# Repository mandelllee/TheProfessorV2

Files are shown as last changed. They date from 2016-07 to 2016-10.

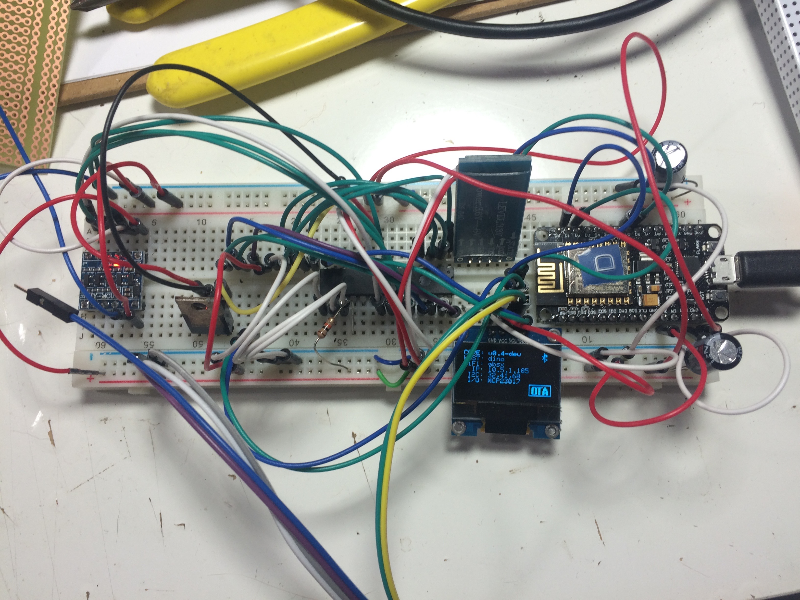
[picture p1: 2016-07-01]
images/IMG_1917.jpg

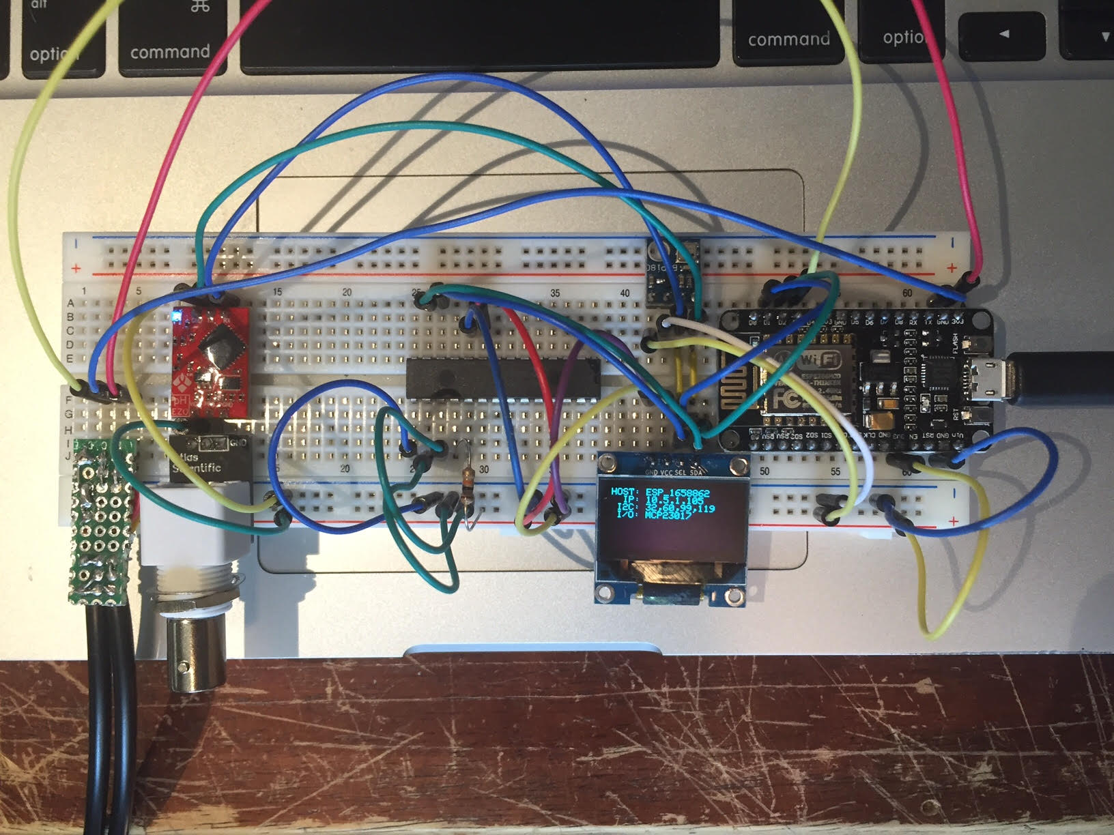
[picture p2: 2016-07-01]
images/breadboard_leaflift_alpha.jpg

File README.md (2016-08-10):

#Arduino-core for leaflift platform

# Setup #
1. Install USB drivers [CP210x USB to UART Bridge VCP Drivers](https://www.silabs.com/products/mcu/Pages/USBtoUARTBridgeVCPDrivers.aspx)
2. Copy libraries to ~/Documents/Arduino/library/ 

# Supported Boards #
* NodeMCU 1.0 (ESP8266-12E)
* Adafruit HUZZAH (ESP8266-12E)

# Uploading to boards - Step by step  #

## NodeMCU 1.0 (ESP-12E Module) ##
0. arduino ide board manager
    http://arduino.esp8266.com/versions/2.2.0/package_esp8266com_index.json
    https://adafruit.github.io/arduino-board-index/package_adafruit_index.json
1. Select board from Tools > Board:
2. Click ( > ) to upload, board will reset when done

##  Adafruit HUZZAH ESP8266 ##
1. Select board from Tools > Board:
2. Put the Board in program mode on bootloader 
*(hold GPIO0 button then bress reset holding GPIO0 till after reset is released)*
3. Click ( > ) to upload, board will reset when done

# Tools for graphics #
[Tool for creating PROGMEM images](http://javl.github.io/image2cpp/)

# Other resources #
* https://github.com/gnulabis/UTFT-ESP8266
* https://github.com/esp8266/Arduino
* https://github.com/nodemcu/nodemcu-flasher

```
#!text
ESP8266 boot details

reset causes:
        0:
        1: normal boot
        2: reset pin
        3: software reset
        4: watchdog reset

    boot device:
        0:
        1: ram
        3: flash - See more at: http://www.esp8266.com/viewtopic.php?p=2096#p2112

struct bootflags
{
    unsigned char raw_rst_cause : 4;
    unsigned char raw_bootdevice : 4;
    unsigned char raw_bootmode : 4;

    unsigned char rst_normal_boot : 1;
    unsigned char rst_reset_pin : 1;
    unsigned char rst_watchdog : 1;

    unsigned char bootdevice_ram : 1;
    unsigned char bootdevice_flash : 1;
};
struct bootflags bootmode_detect(void) {
    int reset_reason, bootmode;
    asm (
        "movi %0, 0x60000600\n\t"
        "movi %1, 0x60000200\n\t"
        "l32i %0, %0, 0x114\n\t"
        "l32i %1, %1, 0x118\n\t"
        : "+r" (reset_reason), "+r" (bootmode) /* Outputs */
        : /* Inputs (none) */
        : "memory" /* Clobbered */
    );

struct bootflags flags;

    flags.raw_rst_cause = (reset_reason&0xF);
    flags.raw_bootdevice = ((bootmode>>0x10)&0x7);
    flags.raw_bootmode = ((bootmode>>0x1D)&0x7);

    flags.rst_normal_boot = flags.raw_rst_cause == 0x1;
    flags.rst_reset_pin = flags.raw_rst_cause == 0x2;
    flags.rst_watchdog = flags.raw_rst_cause == 0x4;

    flags.bootdevice_ram = flags.raw_bootdevice == 0x1;
    flags.bootdevice_flash = flags.raw_bootdevice == 0x3;

    return flags;

} - See more at: http://www.esp8266.com/viewtopic.php?p=2096#p2112

```

##API Status ##
http://www.nordicsemi.com/eng/Products/Bluetooth-low-energy/nRF51822#Downloads

## Openshift Overview ##
* https://developers.openshift.com/managing-your-applications/

## Nordicware BLE ##
* http://www.waveshare.com/wiki/NRF51822_Eval_Kit
* http://www.nordicsemi.com/eng/Products/Bluetooth-low-energy/nRF51822#Downloads
* http://infocenter.nordicsemi.com/pdf/nRF51822_PB_v2.5.pdf
* https://github.com/rogerclarkmelbourne/nRF51822-Arduino

## Data Sheets ##

[Provisioned Devices](https://docs.google.com/spreadsheets/d/1kAXJa40VPameiitzwAIrNPWsr5kDdviN59xv5x8yYJM/edit#gid=0)

[Recorded Data](https://docs.google.com/spreadsheets/d/1Yr3d8pXQllWeyCImAO6XK0u_NgsKmbjGjc9SEn9wM3I/edit#gid=87589501)

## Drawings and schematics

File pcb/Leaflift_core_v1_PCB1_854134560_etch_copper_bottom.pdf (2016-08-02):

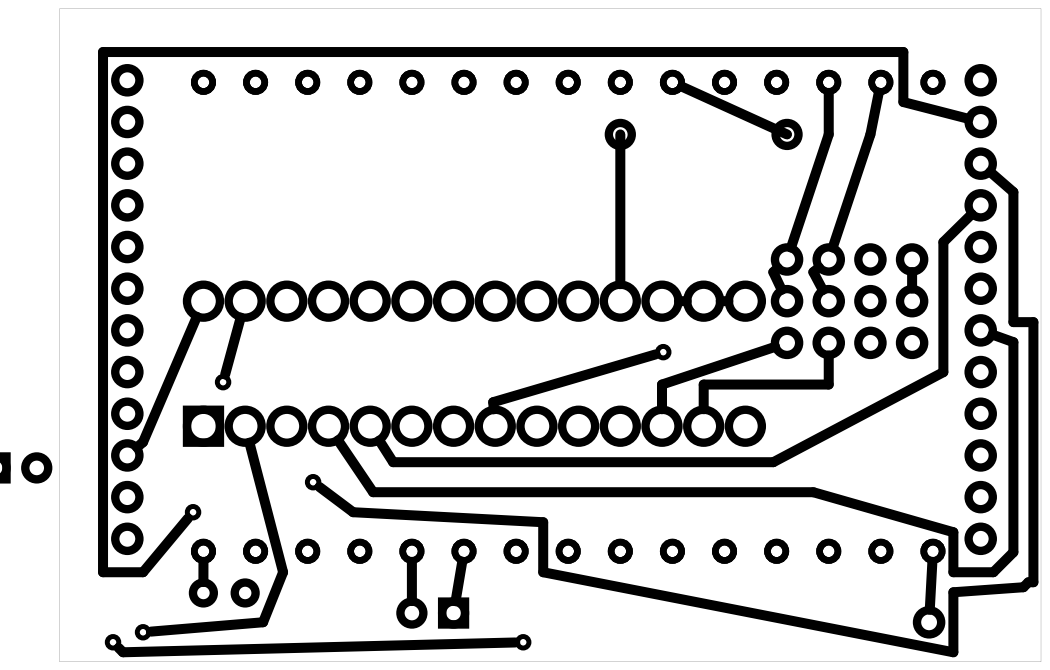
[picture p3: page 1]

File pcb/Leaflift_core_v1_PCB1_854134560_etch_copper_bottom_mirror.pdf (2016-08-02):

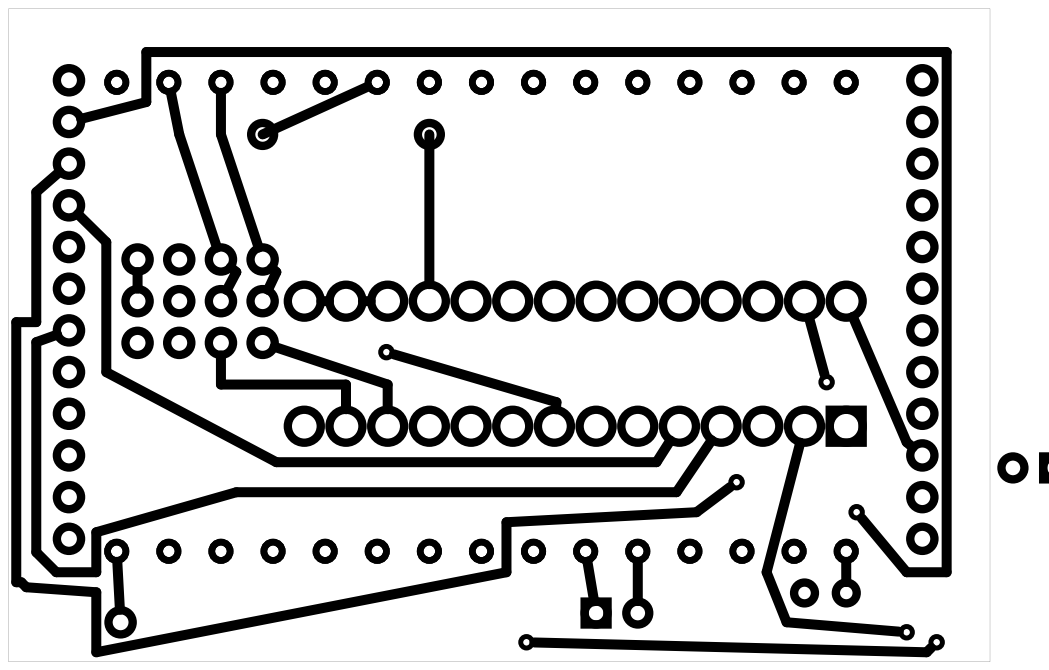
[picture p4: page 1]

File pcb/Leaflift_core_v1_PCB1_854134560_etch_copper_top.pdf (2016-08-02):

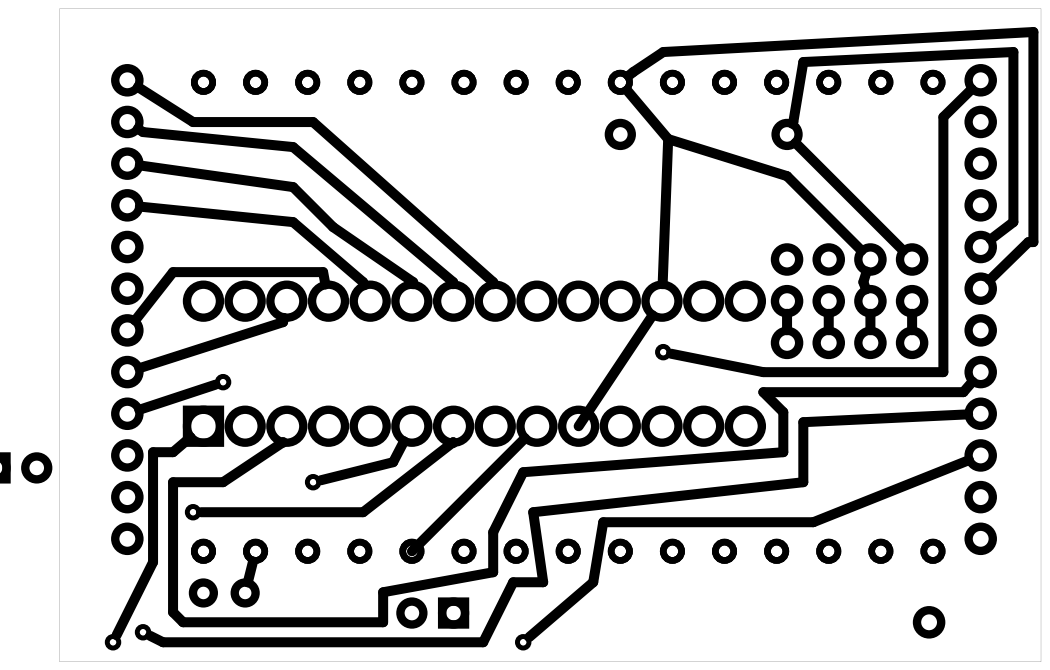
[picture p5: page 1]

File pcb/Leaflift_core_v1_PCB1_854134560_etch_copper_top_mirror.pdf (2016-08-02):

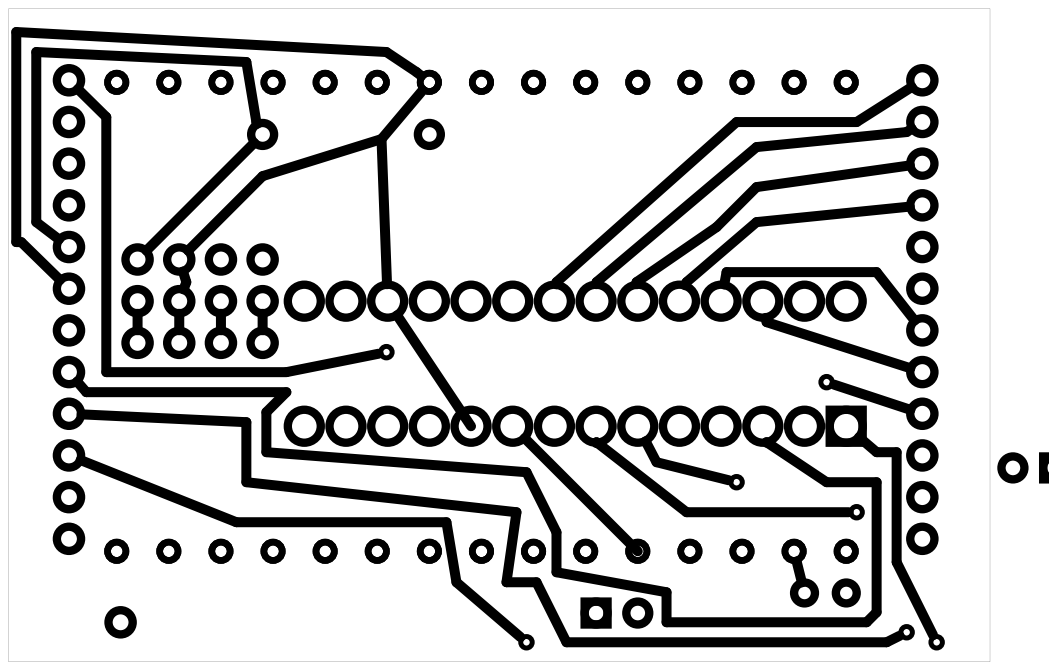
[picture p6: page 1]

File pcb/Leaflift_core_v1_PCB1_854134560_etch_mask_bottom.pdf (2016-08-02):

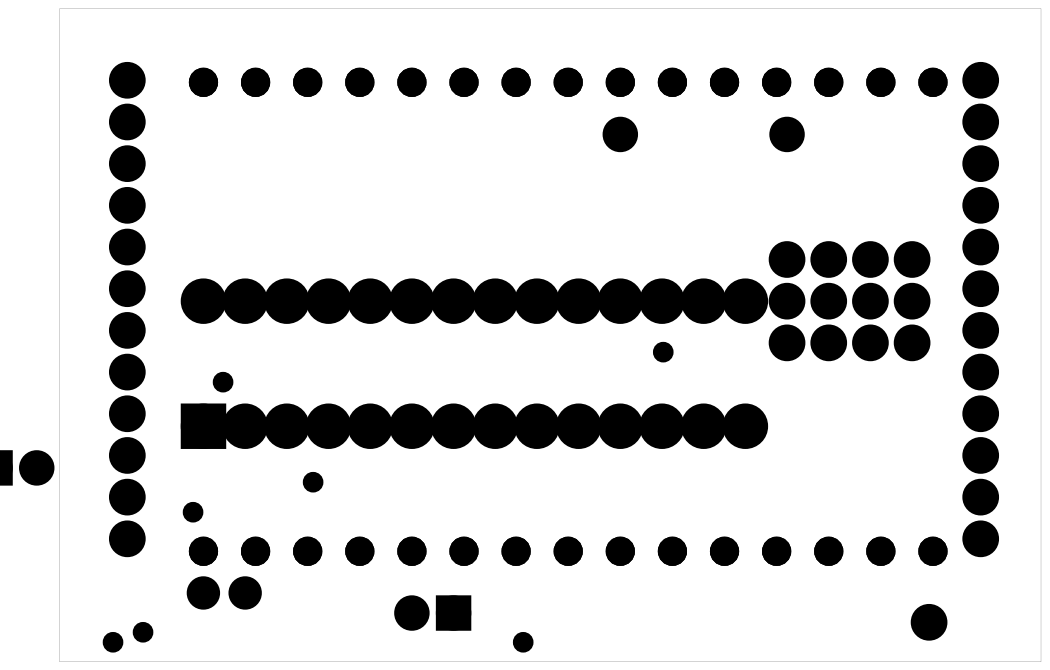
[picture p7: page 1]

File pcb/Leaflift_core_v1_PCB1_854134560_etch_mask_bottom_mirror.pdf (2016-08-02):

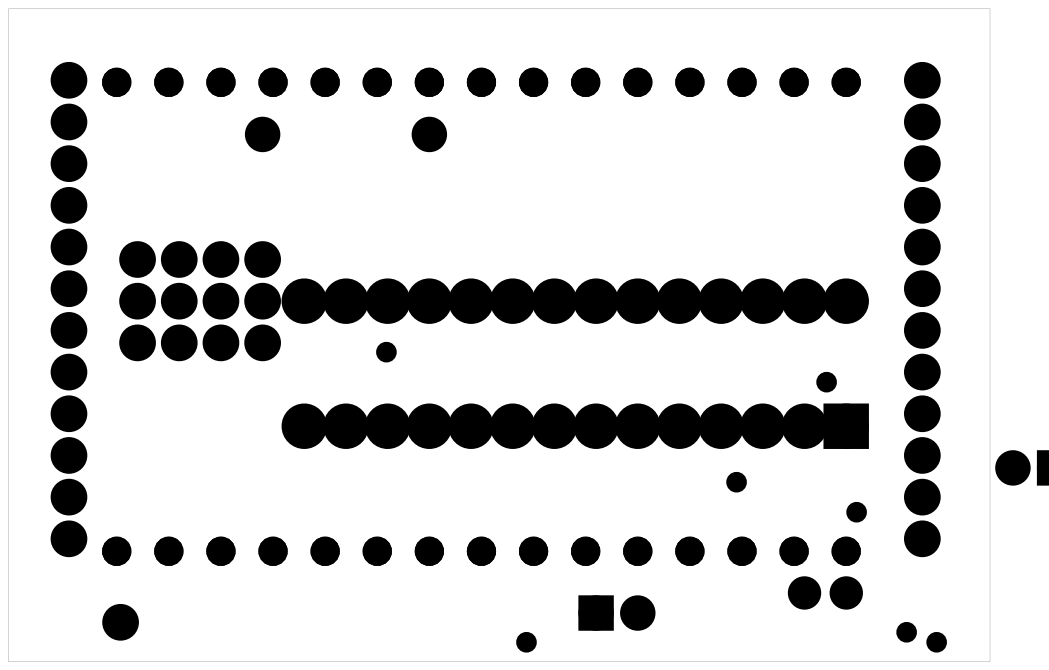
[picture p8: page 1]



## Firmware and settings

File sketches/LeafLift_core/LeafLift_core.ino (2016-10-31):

//      _                 __   _     _  __ _
//     | |               / _| | |   (_)/ _| |
//     | |     ___  __ _| |_  | |    _| |_| |_
//     | |    / _ \/ _` |  _| | |   | |  _| __|
//     | |___|  __/ (_| | |   | |___| | | | |_
//     \_____/\___|\__,_|_|   \_____/_|_|  \__|
//
//     Arduino-Core
//
//          I2C    I2C   1WIRE
//          SDA    SCL   Temp   DHT                           Rx2   Tx2   Rx0   Tx0
//    16  : 5    : 4   : 0    : 722   : 3v  : GND : 14  : 12  : 13  : 15  : 3   : 1   : GND : 3v  :
//  |--------------------------------------------------------------------------------------------|
//  |                                                                                            |
//  |                                                                                            |
//  |__________________                                                                          |
//  |___               |                                                                         |-----
//  |__   |            |                                                                         |     |
//   __|  | ESP8266    |   Node MCU v1.0                                                         | USB |
//  |__|  |            |                                                                         |     |
//   __|__|            |                                                                         |     |
//  |__________________|                                                                         |-----
//  |                                                                                            |
//  |                                                                                            |
//  |                                                                                            |
//  |--------------------------------------------------------------------------------------------|
//    A   : n/a  : n/a : 10  : 9   : MOSI : CS  : MISO : SCLK : GND : 3v : EN : RST : GND : Vin
//                                   SPI    SPI   SPI    SPI
//
//
//        I2C   I2C
//   NC : SDA : SCL : GND : 3v : 7  : 6  : 5  : 4  : 3  : 2  : 1  : 0  
//  ----------------------------------------------------------------------------------- 
//  |                                                                                 |
//  |                                                                                 |
//  |                                                                                / 
//  |                            MCP23017                                           | 
//  |                                                                                \ 
//  |                                                                                 |
//  |                                                                                 |
//  ----------------------------------------------------------------------------------- 
//   A0 : A1 : A3 : RST : INTB : INTA : 0    : 1    : 2    : 3    : 4   : 5   : 6   : 7
//                  10KΩ                Light  Pump   Drain Doser   AC1   AC2   AC3   Ac4
//   GND  GND  GND  GND
//   (I2C Addr 32)

String VERSION = "0.0-cape";

String BOARD_ID = "";

bool TEST_MODE = false;
String chip_id = "";
String _hostname = "";


int _now = 0;
/**
   This will set the value _now using the api

 **/
#include <Wire.h>
#include <Adafruit_Sensor.h>
#include <Adafruit_TSL2561_U.h>
#include <Adafruit_BMP085.h>
#include <OneWire.h>

#define _TASK_SLEEP_ON_IDLE_RUN
#define _TASK_STATUS_REQUEST
#include <TaskScheduler.h>
#include "leaflift_EC.h"

#include <ArduinoJson.h>



int oneWirePin = 0;
OneWire  ds(oneWirePin);  //a 2.2K resistor is necessary for 3.3v on the signal line, 4.7k for 5v


Scheduler ts;
Scheduler sensorScheduler;

#include "leaflift_crypto.h"

#include "Adafruit_MCP23017.h"
#include "leaflift_switches.h"


String API_HOST = "api-quadroponic.rhcloud.com";
int API_PORT = 80;
//char API_HOST[] = "192.168.0.10";
//int API_PORT = 3000;

bool SEND_DATA_TO_API = true;
int SEND_DATA_INTERVAL = 10000;

bool _soilSensorEnabled = false;

double temp_c = 0.00;
double ph_value_double = 0.00;


int i2c_devices[10];
int i2c_device_count = 0;
String currentDisplayText = "";
#include <WiFiUdp.h>
#include <ArduinoOTA.h>
bool _renderDisplayEnabled = true;

bool _enableOTAUpdate = true;
bool _phSensorEnabled = false;
bool _uptime_display = true;
String uptime_string = "";
bool _luxSensorEnabled = false;
bool _BMP085Enabled = false;
bool _flowCounterEnabled = false;
bool _ECSensorEnabled = false;

#include <SoftwareSerial.h>
SoftwareSerial BT(14, 12);
// creates a "virtual" serial port/UART
// connect BT module TX to D10
// connect BT module RX to D11
// connect BT Vcc to 5V, GND to GND

Adafruit_MCP23017 mcp;


#include <ESP8266mDNS.h>
#include <ESP8266WiFi.h>
#include <WiFiClient.h>
#include <ESP8266WebServer.h>


#include "leaflift_ADS1X15.h"

const char* ssid     = "Betsy's wifi";
const char* password = "ninjaturtle";
String ipAddressString = "";
ESP8266WebServer server(80);

const char WiFiAPPSK[] = "password";

const char *ap_name      = "Enterprise-D";
const char *ap_passwd    = "1234567890";

void setupWiFi()
{
  //    WiFi.mode(WIFI_AP);
  //    WiFi.softAP(ap_name, ap_passwd);

  WiFi.mode(WIFI_STA);
  connectWiFi();
}

bool promptVisible = false;
int promptTimeout = 0;
String promptTitle;
String promptText;
double promptLength = 0.00;

#include "leaflift_api.h"


unsigned long _tickCount = 0;
#include "flow_counter.h"

Scheduler ticker;

Task tTicker( 1000, TASK_FOREVER, &TickCallback, &ticker, true);

void TickCallback() {
  _tickCount++;
  // if we have counted 60 seconds
  if ( _tickCount % 60 == 0 ) {
  }


  if( _flowCounterEnabled ){
    flowCounterHandler();
  }
  _now++;
}

//const uint16_t aport = 8266;
//WiFiServer TelnetServer(aport);
//WiFiClient Telnet;
//
//
//void printDebug(const char* c){
////Prints to telnet if connected
//  Serial.println(c);
//
//  if (Telnet && Telnet.connected()){
//    Telnet.println(c);
//  } //- See more at: http://www.esp8266.com/viewtopic.php?f=8&t=5597#sthash.ITMN1A9x.dpuf
//}

#include "leaflift_OTA.h"
#include "dht_sensor.h"
#include "sensor.h"


void __setupWiFi() {
  //  WiFi.softAP( "Wi-Fi_" + _hostname.c_str(), "secure" );
  WiFi.mode(WIFI_AP);

  //WiFi.mode(WIFI_STA);

  uint8_t mac[WL_MAC_ADDR_LENGTH];
  WiFi.softAPmacAddress(mac);
  String macID = String(mac[WL_MAC_ADDR_LENGTH - 2], HEX) +
                 String(mac[WL_MAC_ADDR_LENGTH - 1], HEX);
  macID.toUpperCase();
  String AP_NameString = "ESP8266 Thing " + macID;

  char AP_NameChar[AP_NameString.length() + 1];
  memset(AP_NameChar, 0, AP_NameString.length() + 1);

  for (int i = 0; i < AP_NameString.length(); i++)
    AP_NameChar[i] = AP_NameString.charAt(i);

  WiFi.softAP(AP_NameChar, WiFiAPPSK);

  //connectWiFi();
}

void connectWiFi() {

  Serial.println("Connecting to wiFi ssid: " + String( ssid ) + "...");

  displayTextOnDisplay("Connecting to:\n   " + String(ssid) + "...");
  WiFi.begin(ssid, password);

  while (WiFi.status() != WL_CONNECTED) {
    delay(500);
    addTextToDisplay( "." );
  }
  saveIP();
}


void saveIP() {

  IPAddress myAddr = WiFi.localIP();
  byte first_octet = myAddr[0];
  byte second_octet = myAddr[1];
  byte third_octet = myAddr[2];
  byte fourth_octet = myAddr[3];

  ipAddressString = String( String(first_octet) + "." + String(second_octet) + "." + String(third_octet) + "." + String(fourth_octet) );

  Serial.println("IP: " + ipAddressString );

}

int _lastLUXReading;



Adafruit_BMP085 bmp;



void setupBMP085Sensor() {
  if (!bmp.begin()) {
    Serial.println("Could not find a valid BMP085 sensor, check wiring!");
    while (1) {}
  }
}
int _lastTempC;
int _lastTempF;
int _lastAltitude;
int _lastPressure;

double _currentFarenheightEnv = 0.00;
void readBMP085Sensor() {

  Serial.print("Temperature = ");
  Serial.print(bmp.readTemperature());
  Serial.println(" *C");
  _lastTempC = bmp.readTemperature();

  int newVal = (_lastTempC * 1.8) + 32;
  if ( newVal != _lastTempF ) {
    _lastTempF = newVal;
    recordValue( "environment", "bmp180_temp_f", String(_lastTempF), _hostname );
  }

  _lastPressure = bmp.readPressure();
  Serial.print("Pressure = ");
  Serial.print( String(_lastPressure) );
  Serial.println(" Pa");


  _lastAltitude = bmp.readAltitude();

  // Calculate altitude assuming 'standard' barometric
  // pressure of 1013.25 millibar = 101325 Pascal
  Serial.print("Altitude = ");
  Serial.print( String(_lastAltitude) );
  Serial.println(" meters");

  Serial.print("Pressure at sealevel (calculated) = ");
  Serial.print(bmp.readSealevelPressure());
  Serial.println(" Pa");

  // you can get a more precise measurement of altitude
  // if you know the current sea level pressure which will
  // vary with weather and such. If it is 1015 millibars
  // that is equal to 101500 Pascals.
  Serial.print("Real altitude = ");
  Serial.print(bmp.readAltitude(101500));
  Serial.println(" meters");

}
#include "leaflift_soil.h"


void setupIO() {
  mcp.begin();      // use default address 0

  //  mcp.pinMode(7, INPUT);
  //  mcp.pullUp(7, HIGH);  // turn on a 100K pullup internally

  //mcp.pinMode(6, OUTPUT);

  mcp.pinMode(0, OUTPUT);
  mcp.pinMode(1, OUTPUT);
  mcp.pinMode(2, OUTPUT);
  mcp.pinMode(3, OUTPUT);
  mcp.digitalWrite(0, HIGH);
  mcp.digitalWrite(1, HIGH);
  mcp.digitalWrite(2, HIGH);
  mcp.digitalWrite(3, HIGH);

  mcp.pinMode(4, OUTPUT);
  mcp.pinMode(5, OUTPUT);
  mcp.pinMode(6, OUTPUT);
  mcp.pinMode(7, OUTPUT);

  mcp.digitalWrite(4, HIGH);
  mcp.digitalWrite(5, HIGH);
  mcp.digitalWrite(6, HIGH);
  mcp.digitalWrite(7, HIGH);


  mcp.pinMode(8, INPUT);
  mcp.pinMode(9, INPUT);
  mcp.pinMode(10, INPUT);
  mcp.pinMode(11, INPUT);
  //  mcp.pullUp(8, HIGH);
  //  mcp.pullUp(9, HIGH);
  //  mcp.pullUp(10, HIGH);
  //  mcp.pullUp(11, HIGH);

  if ( TEST_MODE ) testSwitches();

  //  delay(200);
  //  mcp.digitalWrite(1, LOW);
  //  delay(2000);
  //  mcp.digitalWrite(1, HIGH);
  //  delay(200);
  //  mcp.digitalWrite(1, LOW);
  //  delay(200);
  //  mcp.digitalWrite(1, HIGH);
  //  delay(200);
  //  mcp.digitalWrite(1, LOW);
  //  delay(200);
  //  mcp.digitalWrite(1, HIGH);
  //  delay(200);
  //  mcp.digitalWrite(1, LOW);
  // delay(200);
  //  mcp.digitalWrite(1, HIGH);

}

void testSwitches() {

  currentDisplayText = "Testing Switches...\n";
  updateDisplay();

  for (int n = 0; n < 8; n++) {
    mcp.digitalWrite( n, HIGH );
  }

  for (int n = 0; n < 8; n++) {
    addTextToDisplay( "MCP[" + String(n) + "]\n" );
    mcp.digitalWrite( n, LOW );
    delay( 2000 );
    mcp.digitalWrite( n, HIGH );
    //delay( 2000 );
  }
}
#include "leaflift_bluetooth.h"

void toggleAllSwitches() {

  delay(250);
  if ( switch_state == 0) {
    switch_state = 1;
    mcp.digitalWrite( 0, LOW );
    mcp.digitalWrite( 1, LOW );
    mcp.digitalWrite( 2, LOW );
    mcp.digitalWrite( 3, LOW );

    mcp.digitalWrite( 4, LOW );
    mcp.digitalWrite( 5, LOW );
    mcp.digitalWrite( 6, LOW );
    mcp.digitalWrite( 7, LOW );

  } else {
    switch_state = 0;
    mcp.digitalWrite( 0, HIGH );
    mcp.digitalWrite( 1, HIGH );
    mcp.digitalWrite( 2, HIGH );
    mcp.digitalWrite( 3, HIGH );
    mcp.digitalWrite( 4, HIGH );
    mcp.digitalWrite( 5, HIGH );
    mcp.digitalWrite( 6, HIGH );
    mcp.digitalWrite( 7, HIGH );
  }
}
void sendStatusJSON( String msg ) {
  Serial.println(msg);
  server.send(200, "text/plain", getJSONStatus( msg ) );
}

String get_i2cString() {
  String i2c_string = "";
  for (int n = 0; n < 10; n++) {
    if ( i2c_devices[n] > 0 ) {
      if (i2c_string.length() > 0) i2c_string += ",";
      i2c_string += "" + String( i2c_devices[n] ) + "";
    }
  }
  return i2c_string;
}


String getJSONStatus( ) {
  return getJSONStatus("");
}

String getJSONStatus( String msg )
{
  String i2c_string = get_i2cString();
  String data = "{\n  \"board_id\":\"" + BOARD_ID + "\",\n  \"chip_id\":\"" + chip_id + "\",\n  \"now\":\"" + String(_now) + "\",\n  \"uptime\":\"" + uptime_string + "\",\n  \"core_version\":\"" + VERSION + "\",\n  \"ip\":\"" + ipAddressString + "\",\n  \"hostname\":\"" + _hostname + "\",\n  \"i2c\":[" + i2c_string + "]";

  data += ",\n  \"api_enabled\": \"" + String(SEND_DATA_TO_API ? "1" : "0") + "\"";
  data += ",\n  \"api_interval\": \"" + String(SEND_DATA_INTERVAL) + "\"";
  data += ",\n  \"api_host\": \"" + String(API_HOST) + "\"";
  data += ",\n  \"api_port\": \"" + String(API_PORT) + "\"";
  data += ",\n  \"ph_sensor\": \"" + String(_phSensorEnabled ? "1" : "0") + "\"";
  data += ",\n  \"EC_sensor\": \"" + String(_ECSensorEnabled ? "1" : "0") + "\"";
  data += ",\n  \"temp_probes\": \"" + String(_enableTempProbes ? "1" : "0") + "\"";
  data += ",\n  \"uptime_display\": \"" + String(_uptime_display ? "1" : "0") + "\"";
  data += ",\n  \"bluetooth\": \"" + String(bluetoothAvailable ? "1" : "0") + "\"";
  data += ",\n  \"ota\": \"" + String(_enableOTAUpdate ? "1" : "0") + "\"";
  data += ",\n  \"lux_sensor\": \"" + String( _luxSensorEnabled ? "1" : "0") + "\"";
  data += ",\n  \"dht_sensor\": \"" + String( _dhtSensorEnabled ? "1" : "0") + "\"";
  data += ",\n  \"soil\": \"" + String( _soilSensorEnabled ? "1" : "0") + "\"";
  data += ",\n  \"soil_sensor\": \"" + String( _soilSensorEnabled ? "1" : "0") + "\"";

  if ( msg.length() > 0) data += ",\n  \"msg\": \"" + msg + "\"";
  data += "\n}";
  return data;
}


String getJSONData( String msg )
{
  String i2c_string = get_i2cString();

  String data =  "{\n";

  data += "  \"hostname\":\"" + _hostname + "\"";
  data += ",\n  \"core_version\":\"" + VERSION + "\"";
  if ( msg.length() > 0) data += ",\n  \"msg\": \"" + msg + "\"";
  data += ",\n";

  data += "  \"now\":\"" + String(_now) + "\",\n";
  data += "  \"sensors\": {";

  // always have a first entry, that way all next ones prefix a comma
  data += "\n    \"uid\": \"000000\"";

  if ( _phSensorEnabled ) data += ",\n    \"ph\": " + String(ph_value_double) + "";

  if ( _enableTempProbes ) {
    data += ",\n    \"probes\": {";
    String probeid = "avg";
    data += "\n      \""+probeid+"\": { \"temp_c\": " + String(temp_c) + " }";
    //data += ",\n    \"temp_c\": " + String(temp_c) + "";

    data += "\n    }";
  }


  if( _flowCounterEnabled ){

    data += ",\n    \"flow\": {";
    data += "\n      \"pin\": \"" + String( flowPin1 ) + "\"";
    data += ",\n      \"count\": \"" + String( flowCounter ) + "\"";
    data += ",\n      \"lpm\": \"" + String( _lastLPM ) + "\"";
    data += ",\n      \"lph\": \"" + String( litersPerHour ) + "\"";
    data += "\n    }";
  }

  if ( _luxSensorEnabled ) {
    data += ",\n    \"tsl2561\": {";
    data += "\n      \"lux\": " + String( _lastLUXReading ) + "";
    data += "\n    }";
  }
  if ( _BMP085Enabled ) {
    data += ",\n    \"bmp085\": {";
    data += "\n      \"temp_c\": " + String( _lastTempC ) + "";
    data += ",\n      \"temp_f\": " + String( _lastTempF ) + "";
    data += ",\n      \"altitude\": " + String( _lastAltitude ) + "";
    data += ",\n      \"pressure\": " + String( _lastPressure ) + "";
    data += "\n    }";
  }
  if ( _ECSensorEnabled ) {
    data += ",\n    \"EC\": {";
    data += "\n      \"ec\": " + String( ec_float ) + "";
    data += ",\n      \"tds\": " + String( tds_float ) + "";
    data += ",\n      \"salinity\": " + String( sal_float ) + "";
    data += ",\n      \"specificGravity\": " + String( sg_float ) + "";
    data += "\n    }";
  }
  if ( _dhtSensorEnabled ) {
    data += ",\n    \"dht11\": {";
    data += "\n      \"dht_temp_f\": " + String( dht_temp_f ) + "";
    //data += "\n      \"dht_temp_c\": " + String( dht_temp_c ) + "";
    data += ",\n      \"dht_humidity\": " + String( dht_humidity ) + "";
    data += "\n    }";
  }
  if ( _soilSensorEnabled ) {
    data += ",\n    \"soil\": { ";
    data += "\n      \"sensors\": { ";
    data += "\n         \"1\":\"" + String( sensorReadings[0] ) + "\"";
    data += ",\n         \"2\":\"" + String( sensorReadings[1] ) + "\"";
    data += ",\n         \"3\":\"" + String( sensorReadings[2] ) + "\"";
    data += ",\n         \"4\":\"" + String( sensorReadings[3] ) + "\"";
    data += "\n      }";

    data += _soilConfigJSON;

    //data += "\"state\":\"" + _soilState + "\"";
    //data += ", \"moisture\":\"" + String(_soilMoistureReading) + "\" ";
    data += "\n    }";


  }
  data += "\n";
  data += "   }\n";
  data += "}\n";
  return data;

}

#include "leaflift_ph.h"


void readTemperatureSensors() {
  byte i;
  byte present = 0;
  byte type_s;
  byte data[12];
  byte addr[8];
  float celsius, fahrenheit;

  Serial.println("Reading temperature probes...");
  if ( !ds.search(addr)) {
    //Serial.println("No more addresses.");
    Serial.println();
    ds.reset_search();
    delay(250);
    return;
  }

  Serial.print("ROM =");
  for ( i = 0; i < 8; i++) {
    Serial.write(' ');
    Serial.print(addr[i], HEX);
  }

  if (OneWire::crc8(addr, 7) != addr[7]) {
    Serial.println("CRC is not valid!");
    return;
  }
  Serial.println();

  // the first ROM byte indicates which chip
  switch (addr[0]) {
    case 0x10:
      Serial.println("  Chip = DS18S20");  // or old DS1820
      type_s = 1;
      break;
    case 0x28:
      Serial.println("  Chip = DS18B20");
      type_s = 0;
      break;
    case 0x22:
      Serial.println("  Chip = DS1822");
      type_s = 0;
      break;
    default:
      Serial.println("Device is not a DS18x20 family device.");
      return;
  }

  ds.reset();
  ds.select(addr);
  ds.write(0x44, 1);        // start conversion, with parasite power on at the end

  delay(1000);     // maybe 750ms is enough, maybe not
  // we might do a ds.depower() here, but the reset will take care of it.

  present = ds.reset();
  ds.select(addr);
  ds.write(0xBE);         // Read Scratchpad

  Serial.print("  Data = ");
  Serial.print(present, HEX);
  Serial.print(" ");
  for ( i = 0; i < 9; i++) {           // we need 9 bytes
    data[i] = ds.read();
    Serial.print(data[i], HEX);
    Serial.print(" ");
  }
  Serial.print(" CRC=");
  Serial.print(OneWire::crc8(data, 8), HEX);
  Serial.println();

  // Convert the data to actual temperature
  // because the result is a 16 bit signed integer, it should
  // be stored to an "int16_t" type, which is always 16 bits
  // even when compiled on a 32 bit processor.
  int16_t raw = (data[1] << 8) | data[0];
  if (type_s) {
    raw = raw << 3; // 9 bit resolution default
    if (data[7] == 0x10) {
      // "count remain" gives full 12 bit resolution
      raw = (raw & 0xFFF0) + 12 - data[6];
    }
  } else {
    byte cfg = (data[4] & 0x60);
    // at lower res, the low bits are undefined, so let's zero them
    if (cfg == 0x00) raw = raw & ~7;  // 9 bit resolution, 93.75 ms
    else if (cfg == 0x20) raw = raw & ~3; // 10 bit res, 187.5 ms
    else if (cfg == 0x40) raw = raw & ~1; // 11 bit res, 375 ms
    //// default is 12 bit resolution, 750 ms conversion time
  }
  celsius = (float)raw / 16.0;
  fahrenheit = celsius * 1.8 + 32.0;
  
  currentFarenheight = fahrenheit;

  
  Serial.print("  Temperature = ");
  Serial.print(celsius);
  Serial.print(" Celsius, ");
  Serial.print(fahrenheit);
  Serial.println(" Fahrenheit");


  if( temp_c != (double)celsius ){
   temp_c = (double)celsius;

    // HACK: since the ph Sensor reports the probe temp, we only want to report if it's not enabled
    if( !_phSensorEnabled ){
      recordValue( "environment", "probe_temp_f", String( fahrenheit ), _hostname );  
    }
  }
  
  
}


void scanI2C() {
  Wire.begin();
  byte error, address;
  Serial.println("Scanning...");
  addTextToDisplay("Scanning i2c...\n");
  i2c_device_count = 0;
  for (address = 1; address < 127; address++ )
  {
    // The i2c_scanner uses the return value of
    // the Write.endTransmisstion to see if
    // a device did acknowledge to the address.
    Wire.beginTransmission(address);
    error = Wire.endTransmission();

    if (error == 0)
    {
      Serial.print("I2C device found at address 0x");
      if (address < 16)
        Serial.print("0");
      Serial.print(address, HEX);

      Serial.print(" [" + String(address) + "]");
      Serial.println("  !");

      addTextToDisplay( " [" + String(address) + "]\n");

      i2c_devices[i2c_device_count] = address;
      i2c_device_count++;
    }
    else if (error == 4)
    {
      Serial.print("Unknow error at address 0x");
      if (address < 16)
        Serial.print("0");
      Serial.println(address, HEX);
    }
  }
  if (i2c_device_count == 0) {
    Serial.println("No I2C devices found\n");
    addTextToDisplay( " No I2C devices found\n");
  } else {
    Serial.println("done\n");
  }
  //delay( 2000 );
}


bool haveIOChip = false;
bool _bluetoothEnabled = false;

#include "hostname_config.h"

bool button1Down = false;
bool button2Down = false;
bool switch1 = false;
bool switch2 = false;

bool button3Down = false;
bool button4Down = false;
bool switch3 = false;
bool switch4 = false;

int n = 0;
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
void loop() {

  //printDebug("Loop");
  handleBluetooth();

  //pinValues = read_shift_regs();



  //handleButtons();
  //
  //  if ( buttonAState == 0 ) {
  //    if ( buttonADown ) {
  //      //
  //      Serial.println("Button A held down");
  //    } else {
  //      buttonADown = true;
  //      BT.println("{\"id\":\"buttonA\",\"state\":\"DOWN\"}");
  //
  //    }
  //  } else if ( buttonADown ) {
  //
  //    Serial.println("Button 4 UP");
  //    Serial.println("Toggling state of switch A ");
  //    BT.println("{\"id\":\"buttonA\",\"state\":\"UP\"}");
  //
  //    //buttonAState = true;
  //    buttonADown = false;
  //    renderDisplay();
  //  }
  //mcp.digitalWrite( 6, buttonADown );
  //readShiftRegister();
  //updateShiftRegister( outValues );
  ts.execute();
  sensorScheduler.execute();
  ticker.execute();

  server.handleClient();

  ArduinoOTA.handle();
}

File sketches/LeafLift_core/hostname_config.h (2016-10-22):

void configureHostname() {

  chip_id = String( ESP.getChipId() );
  //char c[] = chip_id.c_str();

  char c[chip_id.length() + 1];
  memset(c, 0, chip_id.length() + 1);

  for (int i = 0; i < chip_id.length(); i++)
    c[i] = chip_id.charAt(i);

  //generate the MD5 hash for our string
  unsigned char* hash = MD5::make_hash( c );

  //generate the digest (hex encoding) of our hash
  char *md5str = MD5::make_digest(hash, 16);
  free(hash);
  //print it on our serial monitor
  //Serial.println(md5str);
  //Give the Memory back to the System if you run the md5 Hash generation in a loop
  BOARD_ID = md5str;

  free(md5str);

  //hostname = ESP.getChipId()
  //char hostname [12+1];
  //_hostname = "ESP_" + chip_id;

  if ( chip_id == "13904180" ) {
    _hostname = "soil";
    _soilSensorEnabled = true;

  } else if ( chip_id == "16044072" ) {
    _hostname = "hippo";

    //API_HOST = "10.5.1.147";
    //API_PORT = 3000;

    _phSensorEnabled = false;
    _enableTempProbes = true;
    _dhtSensorEnabled = false;

    useIOForSoilSensor = true;
    soilSensorPin1 = 0;
    soilSensorPin2 = -1;
    soilSensorPin3 = -1;
    
// DRY    "1":"310",
//         "2":"416",
//         "3":"0",
//         "4":"0"
// WET        "1":"240",
//         "2":"402",
//         "3":"0",
//         "4":"0"
    int dry[] = {246,223,281,0};
    int wet[] = {265,323,321,0};

    _soilSensorEnabled = true;
    soilSensorLabel[0] = "mint";
    soilSensorLabel[1] = "_";
    soilSensorLabel[2] = "_";

    _soilConfigJSON = ",\n      \"config\": { \n";
    _soilConfigJSON+= "        \"io\": { \n";
    _soilConfigJSON+= "          \"controller\":\""+String(useIOForSoilSensor==true?"mcp":"gpio")+"\",\n";
    _soilConfigJSON+= "          \"pins\": { \n";
    _soilConfigJSON+= "            \"1\":\""+String(soilSensorPin1)+"\",\n";
    _soilConfigJSON+= "            \"2\":\""+String(soilSensorPin2)+"\",\n";
    _soilConfigJSON+= "            \"3\":\""+String(soilSensorPin3)+"\",\n";
    _soilConfigJSON+= "            \"4\":\""+String(soilSensorPin4)+"\"\n";
    _soilConfigJSON+= "           }\n";
    _soilConfigJSON+= "         }\n";
    _soilConfigJSON+= "       },\n";
    _soilConfigJSON+= "      \"calibration\": { \n";
    _soilConfigJSON+= "        \"label\": { \n";
    _soilConfigJSON+= "          \"1\":\""+soilSensorLabel[0]+"\",\n";
    _soilConfigJSON+= "          \"2\":\""+soilSensorLabel[1]+"\",\n";
    _soilConfigJSON+= "          \"3\":\""+soilSensorLabel[2]+"\",\n";
    _soilConfigJSON+= "          \"4\":\""+soilSensorLabel[3]+"\"\n";
    _soilConfigJSON+= "         },\n";
    _soilConfigJSON+= "        \"dry\": { \n";
    _soilConfigJSON+= "          \"1\":\""+String(dry[0])+"\",\n";
    _soilConfigJSON+= "          \"2\":\""+String(dry[1])+"\",\n";
    _soilConfigJSON+= "          \"3\":\""+String(dry[2])+"\",\n";
    _soilConfigJSON+= "          \"4\":\""+String(dry[3])+"\"\n";
    _soilConfigJSON+= "         },\n";
    _soilConfigJSON+= "        \"wet\": { \n";
    _soilConfigJSON+= "          \"1\":\""+String(wet[0])+"\",\n";
    _soilConfigJSON+= "          \"2\":\""+String(wet[1])+"\",\n";
    _soilConfigJSON+= "          \"3\":\""+String(wet[2])+"\",\n";
    _soilConfigJSON+= "          \"4\":\""+String(wet[3])+"\"\n";
    _soilConfigJSON+= "        }\n";
    _soilConfigJSON+= "      }\n";


  } else if ( chip_id == "1770948" ) {
    _hostname = "piru";
    _soilSensorEnabled = false;
    _phSensorEnabled = true;
    _enableTempProbes = true;
    _dhtSensorEnabled = true;
    _luxSensorEnabled = true;
    _ECSensorEnabled = true;
    _BMP085Enabled = true;

  } else if ( chip_id == "13382423" ) {

    _hostname = "EastVillage";
    _luxSensorEnabled = true;
    _dhtSensorEnabled = true;
  
  } else if ( chip_id == "12601523" ) {
    _hostname = "pirupower";


  } else if ( chip_id == "1555028" ) {
    _hostname = "ford";
    
    _phSensorEnabled = false;
    _enableTempProbes = true;
    _flowCounterEnabled = false;

    _dhtSensorEnabled = true;
    soilSensorPin1 = 0;
    soilSensorPin2 = -1;
    soilSensorPin3 = -1;
    _soilSensorEnabled = true;
    soilSensorLabel[0] = "yoyo1";

    int dry[] = {1343,0,0,0};
    int wet[] = {15340,0,0,0};
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

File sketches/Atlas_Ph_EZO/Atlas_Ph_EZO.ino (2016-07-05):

#include <OneWire.h>
#include <ESP8266mDNS.h>

double temp_c = 0.00;
String powerState = "";
float voltValue = 0.0;
bool promptVisible = false;
int promptTimeout=0;
String promptTitle;
String promptText;
double promptLength=0.00;
String currentDisplayText = "";


// PINS


//I2C 
// SDA =4 ?accurate
// SCL =5 ?accurate

int flowPin1 = 2;

int oneWirePin = 0;


// IDENTITY
//TODO: this should be stired in the EEPROM upon setup.
String _userid = "proto1";



// ---------- START WEB --------------------
#include <ESP8266WiFi.h>
#include <ESP8266WebServer.h>

const char* ssid     = "gbsx";
const char* password = "OrlandoNakazawa!";
String ipAddressString = "";
ESP8266WebServer server(80);

void connectWiFi() {

  displayTextOnDisplay("wiFi:" + String(ssid) + "...");
  WiFi.begin(ssid, password);

  while (WiFi.status() != WL_CONNECTED) {
    delay(500);
    addTextToDisplay( "." );
  }
  saveIP();
}
void saveIP() {

  IPAddress myAddr = WiFi.localIP();
  byte first_octet = myAddr[0];
  byte second_octet = myAddr[1];
  byte third_octet = myAddr[2];
  byte fourth_octet = myAddr[3];

  ipAddressString = String( String(first_octet) + "." + String(second_octet) + "." + String(third_octet) + "." + String(fourth_octet) );
}


void recordPh( double input ) {
  Serial.println("pH Changed: " + String(input) );

  String url = "/garden/garden.php?uid=" + _userid + "&action=ph&value=" + String(input) + "&tempc=" + String(temp_c) + "&vcc=" + String(voltValue) + "";
  char host[] = "gbsx.net";

  // Use WiFiClient class to create TCP connections
  WiFiClient client;
  const int httpPort = 80;
  if (!client.connect(host, httpPort)) {
    Serial.println("connection failed");
    return;
  }

  // We now create a URI for the request
  Serial.print("Requesting URL: ");
  Serial.println(url);

  // This will send the request to the server
  client.print( String("GET ") + url + " HTTP/1.1\r\n" +
                "Host: " + host + "\r\n" +
                "Connection: close\r\n\r\n");
  delay(10);

  // Read all the lines of the reply from server and print them to Serial
  while (client.available()) {
    String line = client.readStringUntil('\r');
    Serial.print(line);
  }

  Serial.println();
  Serial.println("closing connection");
}

// ---------- END WEB --------------------


#include <Wire.h>


//void serialEvent() {
//
//  Serial.println("Serial Event");
//
//  received_from_computer = Serial.readBytesUntil(13, computerdata, 20);
//  computerdata[received_from_computer] = 0;
//  serial_event = 1;
//}




#define ph_sensor_address 99 //0x63

String sendPhCommand( char *command ) {

  char out_data[20];
  byte code = 0;
  byte in_char = 0;
  byte i = 0;
  int time_ = 1800;

  Serial.println("sendPhCommand(" + String(command) + ")...");
  ///addTextToDisplay( "reading pH..." );

  int _time_ = 1800;

  Wire.beginTransmission(ph_sensor_address);
  Wire.write( command );
  Wire.endTransmission();
  delay(_time_);
  Wire.requestFrom(ph_sensor_address, 20, 1);
  code = Wire.read();
  Serial.println("Response:[" + String(code) + "]" );
  switch (code) {
    case 1:
      Serial.println("Success"); break;
    case 2: Serial.println("Failed");
      break;
    case 254: Serial.println("Pending");
      break;
    case 255: Serial.println("No Data");
      break;
  }
  while (Wire.available()) {
    in_char = Wire.read();
    out_data[i] = in_char; i += 1;
    if (in_char == 0) {
      Wire.endTransmission(); break;
    }
  }
  return String( out_data );
}

char volt_string[16] = "";
char ph_string[16] = "";
char temp_c_string[16] = "";

float ph_value_float;
double ph_value_double;
String ph = "";
String ph_status = "";
String ph_info = "";
String ph_cal = "";


void readPhSensor() {
  //ph_info = sendPhCommand( "I" );
  //ph_cal = sendPhCommand( "Cal,?" );

  //ph_status = sendPhCommand( "Status" );
  //parseStatus( ph_status );

//  Serial.println("Status: " + ph_status );
//  Serial.println("Cal: " + ph_cal );
//  Serial.println("Info: " + ph_info );

Serial.println("Current temp: " + String(temp_c) );
if( temp_c > 0.00 ){

    char v[8] = "";
    String val = "T,"+ String( temp_c );
    val.toCharArray( v,8);
    
    sendPhCommand( v );
} else {
  sendPhCommand( "T,25.00" );
}

  ph = sendPhCommand( "R" );

  float p = ph.toFloat();


  double new_ph_double = roundf( p * 10 ) / 10;

  // is new value different from last ?
  if ( new_ph_double != ph_value_double ) {
    ph_value_double = new_ph_double;
    dtostrf( ph_value_double, 2, 1, ph_string );
    dtostrf( temp_c, 1, 1, temp_c_string );
    updateDisplay();
    
    recordPh( ph_value_double );
  }


}


void parseStatus( String input) {

  String firstVal;

  for (int i = 0; i < input.length(); i++) {
    if (input.substring(i, i + 1) == ",") {
      firstVal = input.substring(0, i);
      powerState = input.substring(i + 1);
      voltValue = input.substring(i + 3).toFloat();

      dtostrf( voltValue, 1, 1, volt_string );

      break;
    }

  }
}



#define _TASK_SLEEP_ON_IDLE_RUN
#define _TASK_STATUS_REQUEST
#include <TaskScheduler.h>
Scheduler ts;
Scheduler ticker;

// Callback methods prototypes
Task tCycle( 10 * 1000, TASK_FOREVER, &SensorReadCallback, &ts, true);
Task tTicker( 1000, TASK_FOREVER, &TickCallback, &ticker, true);


void SensorReadCallback() {
Serial.println("Reading sensors");

  readPhSensor();
  readTemperatureSensors();  
  updateDisplay();
   
}



unsigned long flow1count = 0;

double litersPerMinute = 0.0;
int flowCounter = 0;

#define TICKS_PER_LITER 450.0


void inputHandler()
{
  // total flow
  flow1count +=1;

  flowCounter += 1;

}

void setupInput(){
  pinMode(flowPin1, INPUT_PULLUP);
  attachInterrupt(flowPin1, inputHandler, CHANGE);
}

double currentFarenheight = 0.00;
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

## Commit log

2016-07-01 adding all sketches
    [NodeMCU_test.fzz, nodemcu.fzz]
2016-07-01 moved sketches to sub folder
    [NodeMCU_test.fzz, nodemcu.fzz]
2016-07-01 renamed the core module
    [NodeMCU_test.fzz, nodemcu.fzz]
2016-07-01 Added some images, and detection for BMP180 and Altas Sensor
2016-07-01 Added the ability to upload via Arduino IDE >= v1.6.9
2016-07-01 added board image
2016-07-05 Added example for Atlas Ph Sensor
2016-07-07 added LUX sensor detection and readout at 12c address 57
2016-07-07 adde BMP085 Sensor reading
2016-07-08 integrated ph and temp probes into core
2016-07-11 enabled api reporting for most sensors, & added DHT temp & humidity
2016-07-13 pretty print
2016-07-13 moved hostname config external, added multiple soil sensor code using gpio & 1N6001 diode
2016-07-13 moved soil sensing to it's own task timer
2016-07-14 Added calibration to the sensors.json for soil sensors
2016-07-16 fixed and standardized some of teh JSON sensor data
    [LeafLift_core.ino, hostname_config.h, leaflift_soil.h]
2016-07-18 added analog sensor usage for soil
2016-07-18 Added initial version of PCB (Still incomplete)
    [Leaflift_core_v1.fzz]
2016-07-19 added ADC library
2016-08-02 recording sensor data
2016-08-02 Allowing use of IO controller for powering sensor channels
2016-08-02 added flow meter into the mix
2016-08-02 updates to the PCB
    [Leaflift_core_v1.1.fzz, Leaflift_core_v1.fzz, Leaflift_soil_v1.fzz]
2016-08-03 added dht22 to pepper, and stubbed in a switches header
2016-08-03 added switches.json and piru nodes
2016-10-05 Update details on Piru node's sensors
2016-10-12 Add EC sensor
2016-10-14 Adding ec sensor
2016-10-22 Revert "Changing hostname fillmore to EastVillage"
    This reverts commit 92c45de0c758751e912d041e133eae500629a68e.
    [hostname_config.h]
2016-10-30 Add device object hierarchy
2016-10-31 Update sensor object hierarchy
